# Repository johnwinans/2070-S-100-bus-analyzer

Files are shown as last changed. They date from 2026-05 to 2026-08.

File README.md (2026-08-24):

# 2070-S-100-bus-analyzer

A 120 channel S-100 bus logic analyzer

This project is based on the open source ["gusmanb" Logic Analyzer](https://github.com/gusmanb/logicanalyzer) project from Agustín Gimenez Bernad

I have started a [YouTube playlist](https://www.youtube.com/playlist?list=PL3by7evD3F51xCtWdVP3EZzuDttMwDS_U) of videos about this project and my testing of the board.

By using the software from the gusmanb/logicanalyzer repo, a 120 channel logic analyzer can be assembled by installing 5 Raspberry PI PICO boards on this S-100 card and accessed using a USB cables to a PC and/or WiFi as described in the above gusmanb github project Wiki.

Here is a [CSV of the project BOM](./2070-S-100-bus-analyzer.csv) with Dikikey order numbers. 

NOTE: I used generic male-headers that I got on Amazon and snapped to length.  I only use gold-plated headers.  Anything else is annoying.
Here is a link to the type that I use for most everything: https://a.co/d/02YRvqt7 (Hint: I snap them to length using a flat [Hakko Wire Cutters](https://a.co/d/055L9axg). Then use shunts to hold them in pairs, tripples, or whatever you need so they stay straight and aligned when soldering.)

# Rev 1.0

***NOTICE: As of April 20, 2026 Rev 1.0 of this design has been tested and is a fully functional board.  However, I am making some cosmetic tweaks (silkscreen, better testpoints, and I might shorten the PCB by 1/8"... see my self-critique in the above playlist.)  I will post a release (and remove this message) when I consider it in final form.***

# Rev 2.0

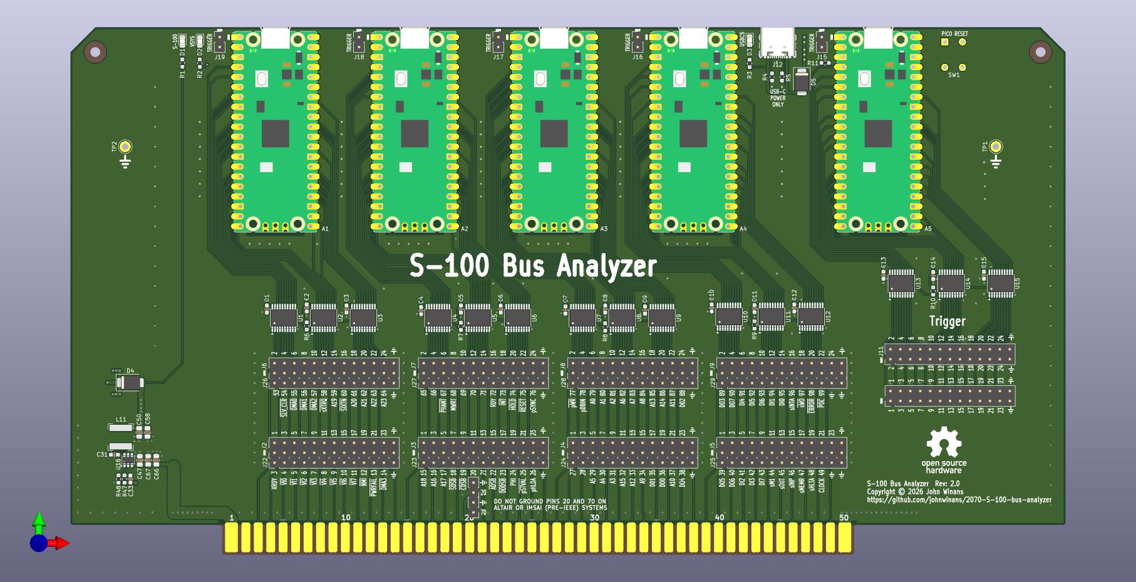
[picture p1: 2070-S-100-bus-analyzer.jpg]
PCB image


***NOTE: This is a release in progress.  It has not yet been tested.***

## Changes
- Change the board height to 5.0 inches to better fit into IEEE card cages.
- Change to use 3-row headers so that signals can be connected to a trigger input at the same time as the normal analyzedr channel with simpler jumper wires.
- Remove the alternate regulator option.
- Add special headers for pins 20 and 70 to make their purpose more obvious.
- Change to use thru-hole ground test-points for easier use with gator-clips.
- Use larger fonts and better-center the signal names.

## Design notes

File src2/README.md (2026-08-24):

# PICO Logic Analyzer Firmware and Applications

This software is based on the [Dr.G Logic Analyzer](https://github.com/gusmanb/logicanalyzer) but altered to add new features.
This implementation uses a protocol that is not compatible with the Dr.G GUI application.

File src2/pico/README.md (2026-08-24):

# A PICO Logic Analyzer

NOTE: This software is based on the [Dr.G Logic Analyzer](https://github.com/gusmanb/logicanalyzer) but altered to add new features.
This implementation uses a protocol that is not compatible with the Dr.G GUI application.

This has been verified by building on a Raspberry PI 4B running Trixie.

This is pre-configured for a PICO2.  
Adjust your build if needed by editing `LogicAnalyzer_Build_Settings.cmake`

1. Install the PICO development toolchain as described at: https://github.com/raspberrypi/pico-setup
1. Clone this REPO and build it using the above PICO toolchain from this directory:
```
mkdir build
cd build
cmake ..
make
```
1. Install the firmware on your PICO: power up your PICO while holding down the BOOTSEL button and then uising `picotool`:
```
picotool load LogicAnalyzer.uf2 -vx
```

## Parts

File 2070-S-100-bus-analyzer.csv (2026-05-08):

Reference | Qty | Value | Exclude from BOM | Footprint | Datasheet | Description | Digi-Key_PN | MPN | Manufacturer
TP1,TP2 | 2 | TestPoint |  | TestPoint:TestPoint_Keystone_5010-5014_Multipurpose |  |  | 2019-RCWCTECT-ND
LOGO1 | 1 | OSHW_Logo | Excluded from BOM | Symbol:OSHW-Logo_11.4x12mm_SilkScreen
J1 | 1 | S-100 Edge Connector | Excluded from BOM | S100-footprints:S100-Edge-Connector
SW1 | 1 | SW_MEC_5E |  | S100-footprints:tactile | https://www.te.com/commerce/DocumentDelivery/DDEController?Action=srchrtrv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 | SWITCH TACTILE SPST-NO 0.05A 24V | 450-1940-ND | 1-1825910-5 | TE Connectivity ALCOSWITCH Switches
R48 | 1 | 30K1 |  | Resistor_SMD:R_0603_1608Metric_Pad0.98x0.95mm_HandSolder | https://yageogroup.com/content/datasheet/asset/file/PYU-RT_1-TO-0-01_ROHS_L | RES SMD 30.1K OHM 1% 1/10W 0603 | 13-RT0603FRE0730K1LCT-ND | RT0603FRE0730K1L | YAGEO
R47 | 1 | 158K |  | Resistor_SMD:R_0603_1608Metric_Pad0.98x0.95mm_HandSolder | https://yageogroup.com/content/datasheet/asset/file/PYU-RT_1-TO-0-01_ROHS_L | RES SMD 158K OHM 1% 1/10W 0603 | 13-RT0603FRE07158KLCT-ND | RT0603FRE07158KL | YAGEO
R11 | 1 | 2K2 |  | Resistor_SMD:R_0603_1608Metric_Pad0.98x0.95mm_HandSolder |  |  | 311-2.20KHRCT-ND | RC0603FR-072K2L | YAGEO
R4,R5 | 2 | 5K1 |  | Resistor_SMD:R_0603_1608Metric_Pad0.98x0.95mm_HandSolder |  |  | CR0603-FX-510ELFCT-ND | CR0603-FX-5110ELF | Bourns Inc.
R1,R2,R3,R6,R7,R8,R9,R10 | 8 | 1K |  | Resistor_SMD:R_0603_1608Metric_Pad0.98x0.95mm_HandSolder | https://yageogroup.com/content/datasheet/asset/file/PYU-RC_GROUP_51_ROHS_L | RES SMD 1K OHM 1% 1/10W 0603 | 311-1.00KHRCT-ND | RC0603FR-071KL | Yageo
U16 | 1 | AP63300 |  | Package_TO_SOT_SMD:SOT-23-6 | https://www.diodes.com/assets/Datasheets/AP63300-AP63301.pdf | IC REG BUCK ADJ 3A TSOT26 | 31-AP63301WU-7CT-ND | AP63301WU-7 | Diodes Incorporated
U1,U2,U3,U4,U5,U6,U7,U8,U9,U10,U11,U12,U13,U14,U15 | 15 | 74LVCH245APW,118 |  | Package_SO:TSSOP-20_4.4x6.5mm_P0.65mm | https://assets.nexperia.com/documents/data-sheet/74LVC_LVCH245A.pdf | IC TXRX NON-INVERT 3.6V 20-TSSOP | 1727-4041-1-ND | 74LVCH245APW,118 | Nexperia USA Inc.
H1,H2 | 2 | Card Ejector |  | MountingHole:MountingHole_2.5mm | https://mm.digikey.com/Volume0/opasdata/d220001/medias/docus/6722/CP-2X_D1.pdf | CARD EJECTOR PCB 1.13" .063" WHT | 492-1025-ND | CP-26 WE | Bivar Inc.
A1,A2,A3,A4,A5 | 5 | RaspberryPi_Pico |  | Module:RaspberryPi_Pico_Common_Unspecified | https://datasheets.raspberrypi.com/pico/pico-datasheet.pdf | RASPBERRY PI PICO 2 RP2350 | 2648-SC1631CT-ND | 2648-SC1631CT-ND | Raspberry Pi
D1,D2,D3 | 3 | LED_Filled |  | LED_SMD:LED_0805_2012Metric_Pad1.15x1.40mm_HandSolder | https://look.ams-osram.com/m/2da6f2ceeebf8fac/original/LG-R971.pdf | LED GREEN DIFFUSED 0805 SMD | 475-LGR971-KN-1CT-ND | LG R971-KN-1-0-20-R18 | ams-OSRAM USA INC.
L11 | 1 | 6.8uH |  | Inductor_SMD:L_Bourns-SRN6028 | https://product.tdk.com/en/system/files | FIXED IND 6.8UH 3.6A 47 MOHM SMD | 445-173057-1-ND | VLS6045EX-6R8M | TDK Corporation
D4,D5 | 2 | SS56F |  | Diode_SMD:D_SMB | https://mm.digikey.com/Volume0/opasdata/d220001/medias/docus/6808/SS56F%20SMAF.PDF | 60V INDEPENDENT TYPE 700MV@5A 5A | 5399-SS56FCT-ND | SS56F | Shenzhen Slkormicro Semicon Co., Ltd.
J12 | 1 | USB4105-GF-A |  | Connector_USB:USB_C_Receptacle_GCT_USB4105-xx-A_16P_TopMnt_Horizontal | https://gct.co/files/drawings/usb4105.pdf | CONN RCP USB2.0 TYP C 16P SMD RA | 2073-USB4105-GF-ACT-ND | USB4105-GF-A | GCT
J2,J3,J4,J5,J6,J7,J8,J9,J10,J11 | 10 | Conn_02x13_Odd_Even |  | Connector_PinHeader_2.54mm:PinHeader_2x13_P2.54mm_Vertical | ~ | Generic connector, double row, 02x13, odd/even pin numbering scheme (row 1 odd numbers, row 2 even numbers), script generated (kicad-library-utils/schlib/autogen/connector/)
J22,J23,J24,J25,J26,J27,J28,J29 | 8 | Conn_01x13 |  | Connector_PinHeader_2.54mm:PinHeader_1x13_P2.54mm_Vertical | ~ | Generic connector, single row, 01x13, script generated (kicad-library-utils/schlib/autogen/connector/)
J13,J14,J15,J16,J17,J18,J19 | 7 | Conn_01x02 |  | Connector_PinHeader_2.54mm:PinHeader_1x02_P2.54mm_Vertical | ~ | Generic connector, single row, 01x02, script generated (kicad-library-utils/schlib/autogen/connector/)
C66,C67 | 2 | 22uF 35V |  | Capacitor_SMD:C_0805_2012Metric_Pad1.18x1.45mm_HandSolder | https://product.tdk.com/system/files/dam/doc/product/capacitor/ceramic/mlcc/catalog/mlcc_commercial_general_en.pdf | CAP CER 22UF 35V X5R 0805 | 445-14428-1-ND | C2012X5R1V226M125AC | TDK
C50,C58 | 2 | 22uF |  | Capacitor_SMD:C_0805_2012Metric_Pad1.18x1.45mm_HandSolder | https://search.murata.co.jp/Ceramy/image/img/A01X/G101/ENG/GRM21BR61A226ME44-01.pdf | CAP CER 22UF 10V X5R 0805 | 490-10746-1-ND | GRM21BR61A226ME44L | Murata Electronics
C47 | 1 | 10uF 25V |  | Capacitor_SMD:C_0805_2012Metric_Pad1.18x1.45mm_HandSolder | https://mm.digikey.com/Volume0/opasdata/d220001/medias/docus/4888/TMK212BBJ106KG-T_SS.pdf | CAP CER 10UF 25V X5R 0805 | 587-2985-1-ND | TMK212BBJ106KG-T | Taiyo Yuden
C33 | 1 | 47pF |  | Capacitor_SMD:C_0603_1608Metric_Pad1.08x0.95mm_HandSolder | https://mm.digikey.com/Volume0/opasdata/d220001/medias/docus/609/CL10C470JB8NNNC_Spec.pdf | CAP CER 47PF 50V C0G/NP0 0603 | 1276-1037-1-ND | CL10C470JB8NNNC | Samsung Electro-Mechanics
C1,C2,C3,C4,C5,C6,C7,C8,C9,C10,C11,C12,C13,C14,C15,C31 | 16 | .1uF |  | Capacitor_SMD:C_0603_1608Metric_Pad1.08x0.95mm_HandSolder | ~ | CAP CER 0.1UF 25V X5R 0603 | 445-6854-1-ND | C1608X5R1E104K | TDK Corporation

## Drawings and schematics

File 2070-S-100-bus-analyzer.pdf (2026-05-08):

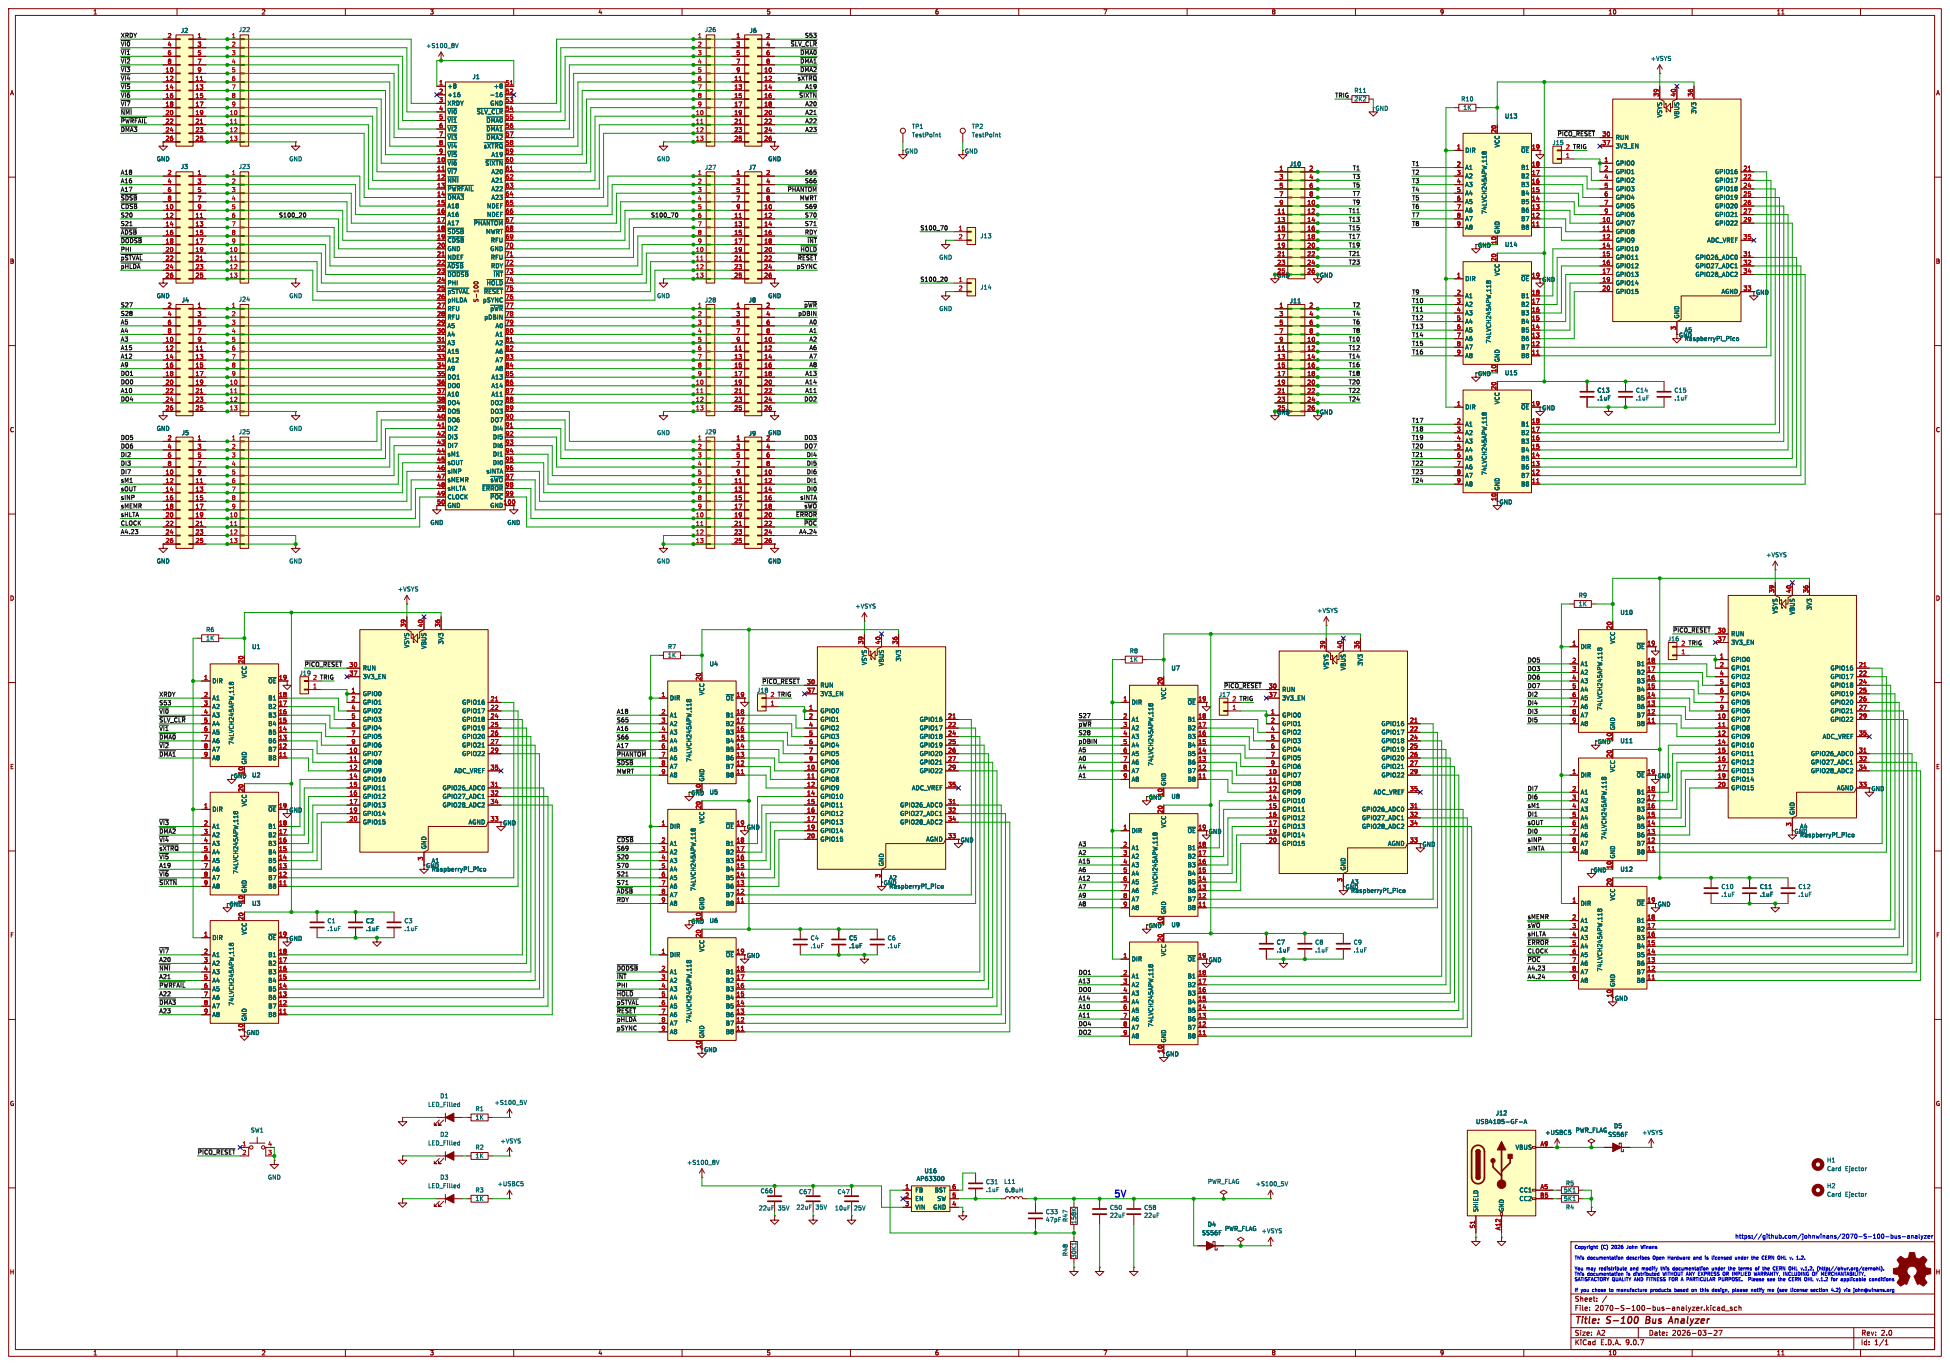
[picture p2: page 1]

J1 +8 1 +16 2 XRDY 3 ~{VI0} 4 ~{VI1} 5 ~{VI2} 6 ~{VI3} 7 ~{VI4} 8 ~{VI5} 9 ~{VI6} 10 ~{VI7} 11 ~{NMI} 12 ~{PWRFAIL} 13 ~{DMA3} 14 A18 15 A16 16 A17 17 ~{SDSB} 18 ~{CDSB} 19 GND 20 NDEF 21 ~{ADSB} 22 ~{DODSB} 23 PHI 24 ~{pSTVAL} 25
GND S-100 +8 1 +16 2 XRDY 3 ~{VI0} 4 ~{VI1} 5 ~{VI2} 6 ~{VI3} 7 ~{VI4} 8 ~{VI5} 9 ~{VI6} 10 ~{VI7} 11 ~{NMI} 12 ~{PWRFAIL} 13 ~{DMA3} 14 A18 15 A16 16 A17 17 ~{SDSB} 18 ~{CDSB} 19 GND 20 NDEF 21 ~{ADSB} 22 ~{DODSB} 23 PHI 24 ~{pSTVAL} 25
-16 52 GND 53 ~{SLV_CLR} 54 ~{DMA0} 55 ~{DMA1} 56 ~{DMA2} 57 ~{sXTRQ} 58 A19 59 ~{SIXTN} 60 A20 61 A21 62 A22 63 A23 64 NDEF 65 NDEF 66 ~{PHANTOM} 67 MWRT 68 RFU 69 GND 70 RFU 71 RDY 72 ~{INT} 73 ~{HOLD} 74 ~{RESET} 75

sINTA 96 ~{sWO} 97 ~{ERROR} 98 ~{POC} 99 GND100

sINTA 96 ~{sWO} 97 ~{ERROR} 98 ~{POC} 99 GND100GND

H2 Card Ejector H1 Card Ejector

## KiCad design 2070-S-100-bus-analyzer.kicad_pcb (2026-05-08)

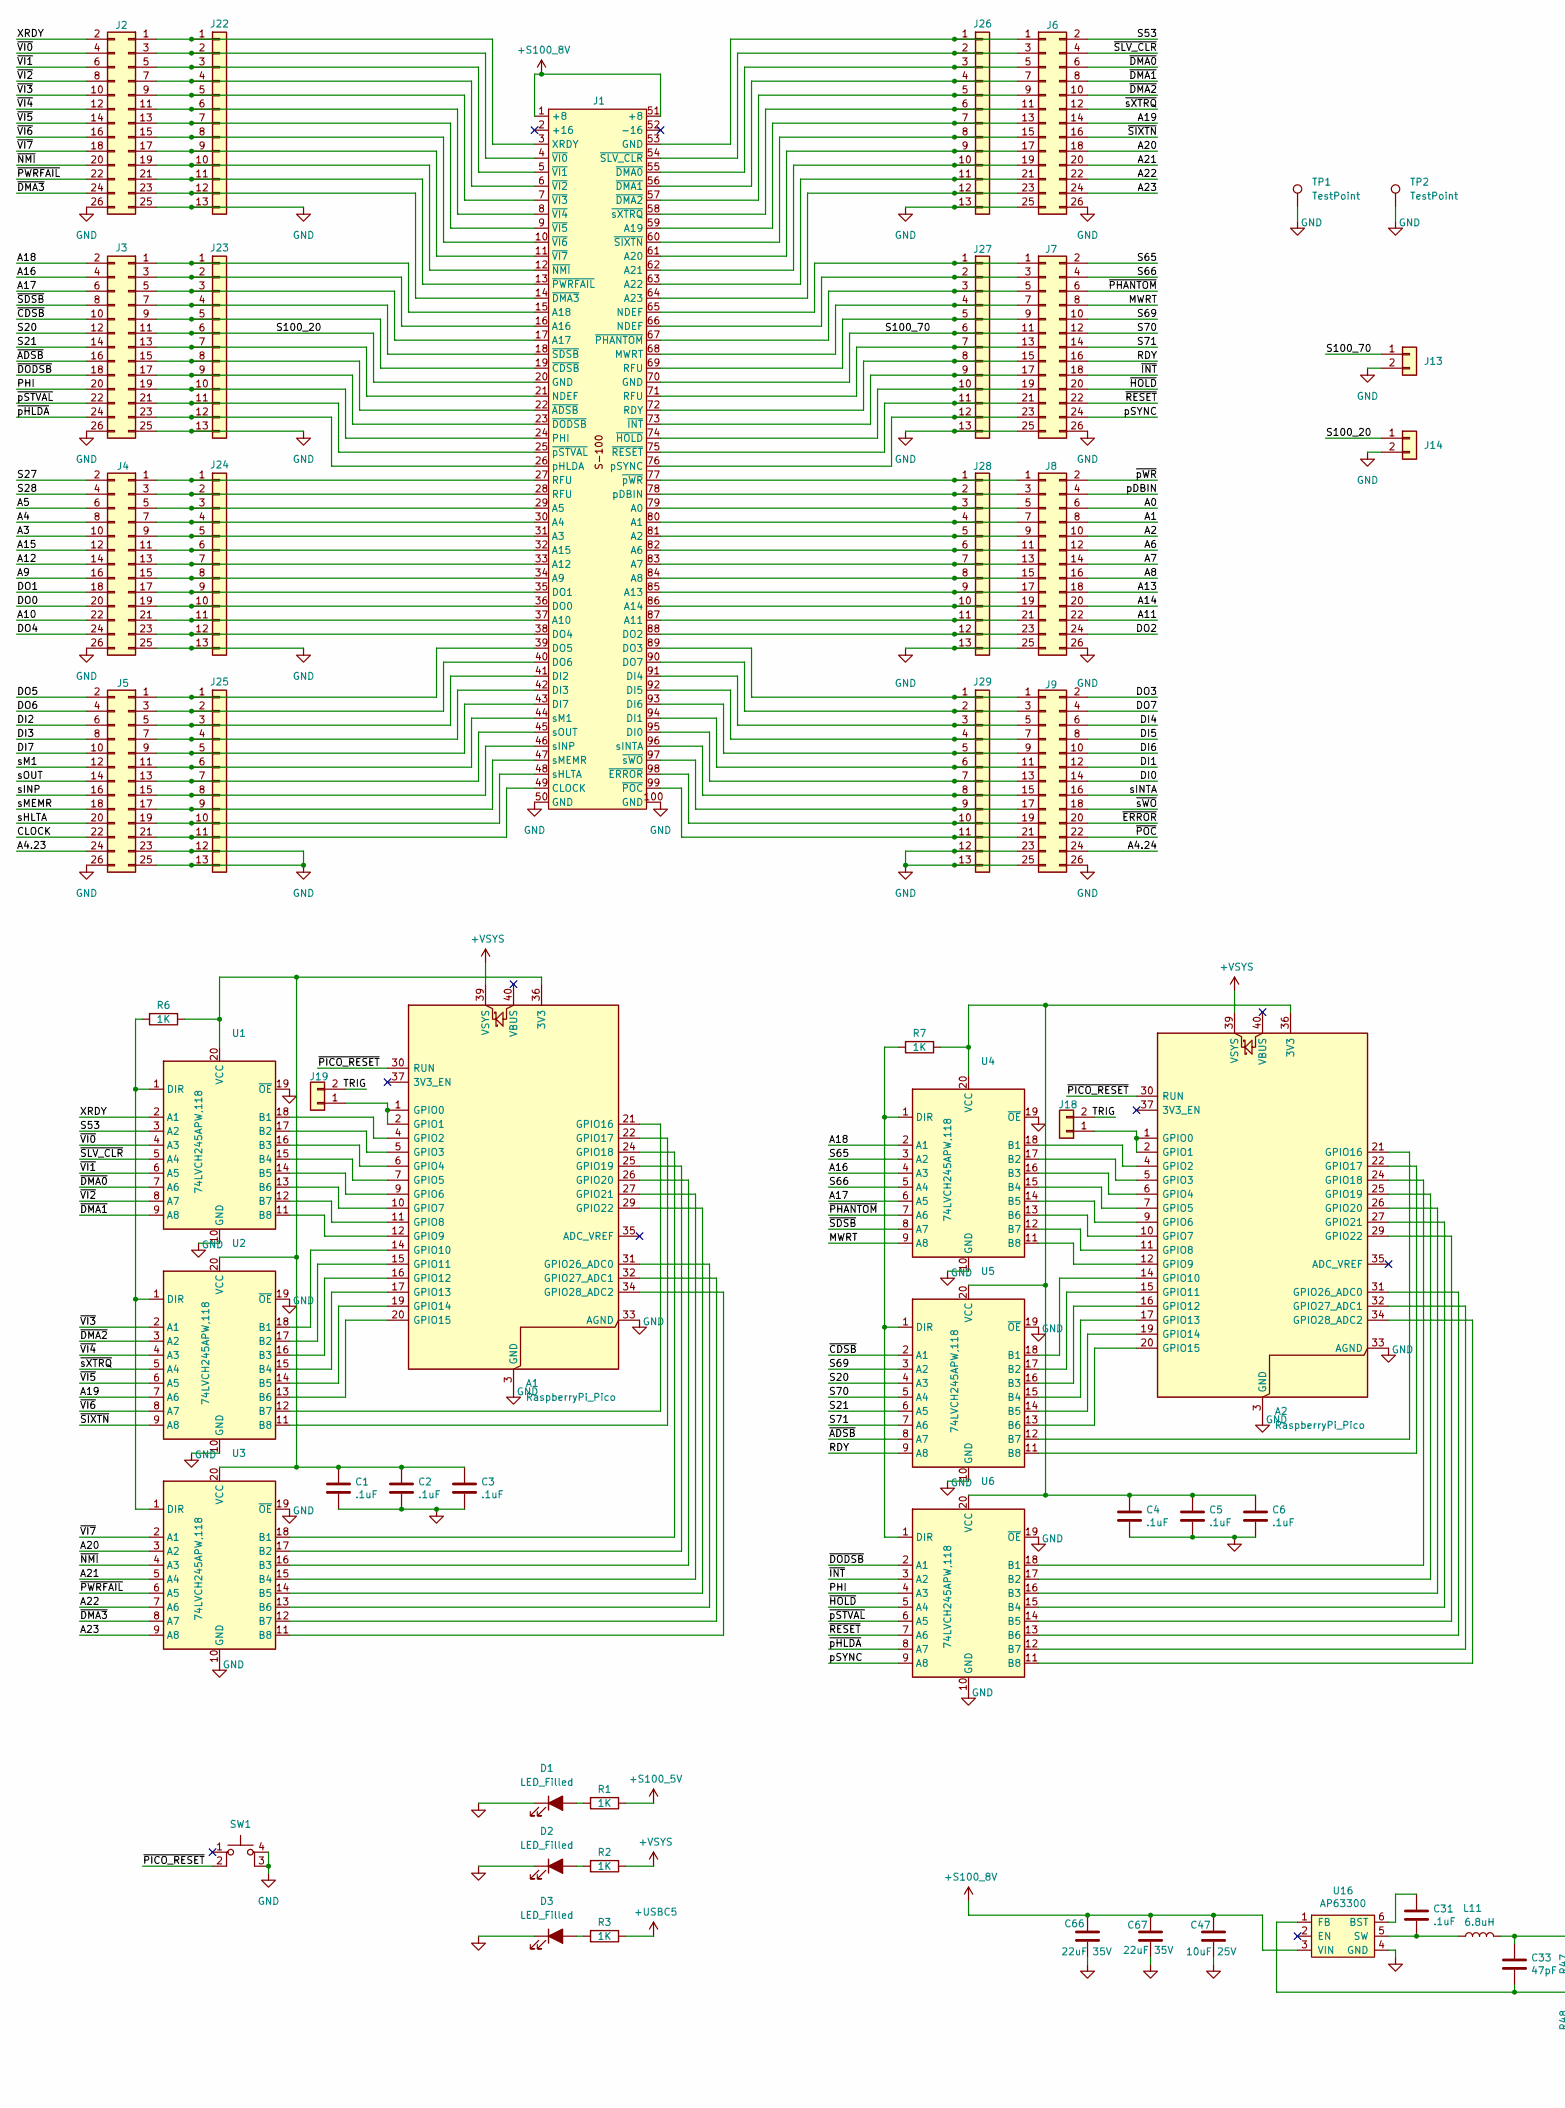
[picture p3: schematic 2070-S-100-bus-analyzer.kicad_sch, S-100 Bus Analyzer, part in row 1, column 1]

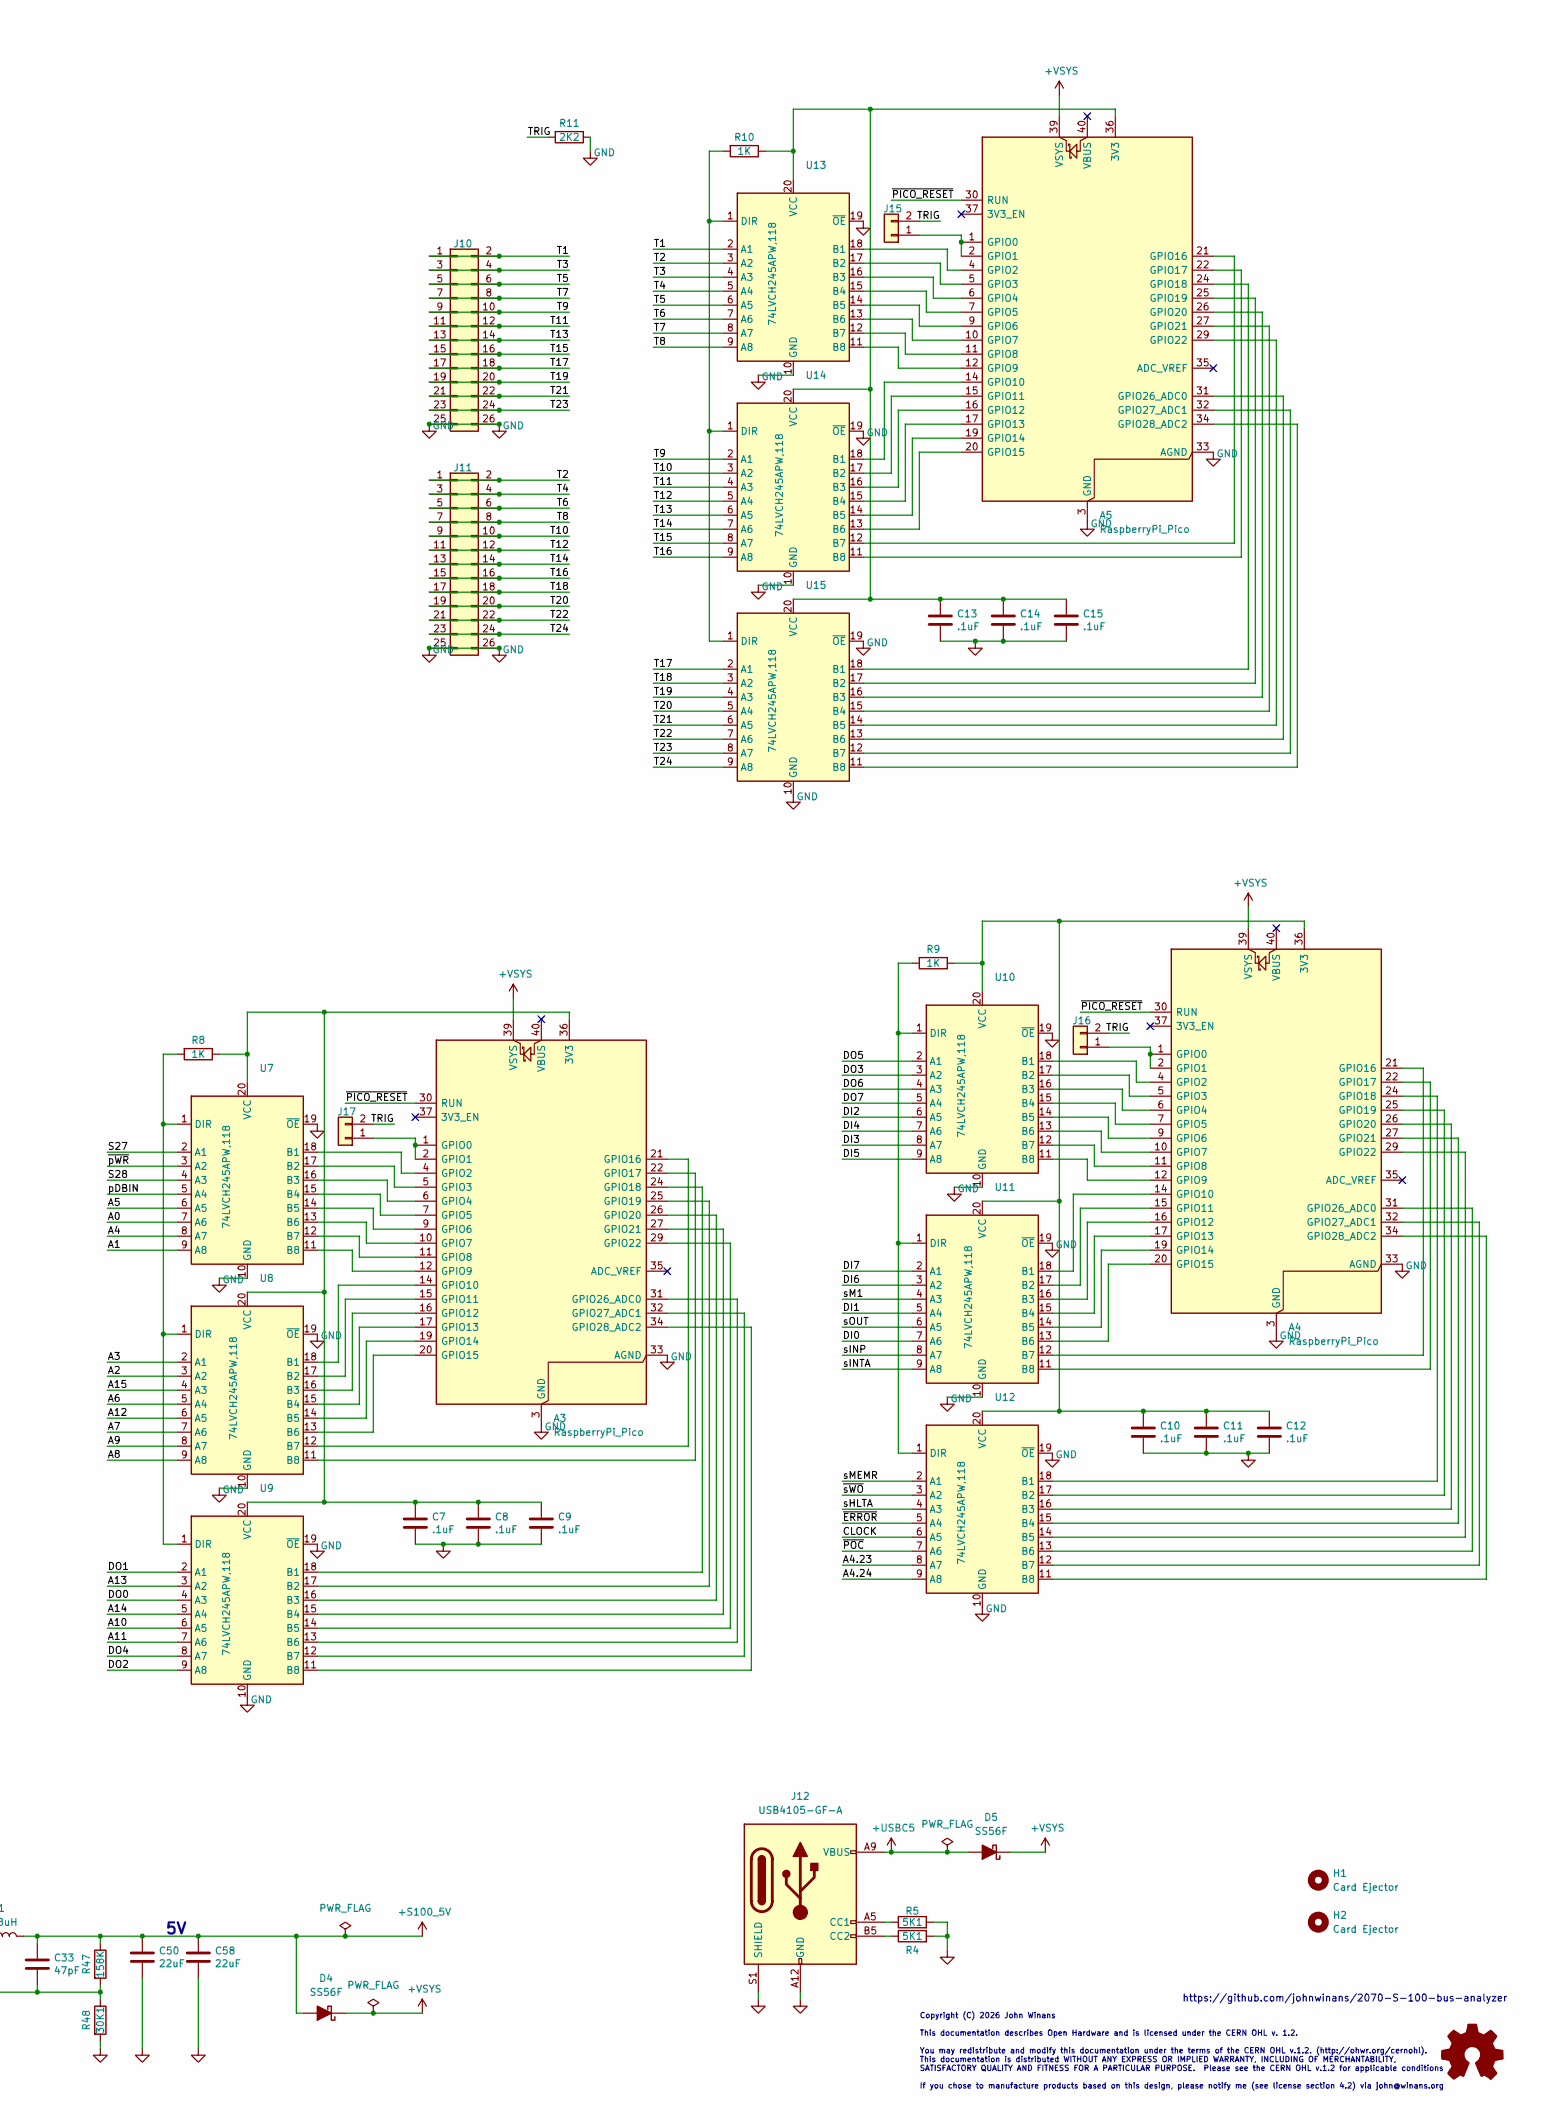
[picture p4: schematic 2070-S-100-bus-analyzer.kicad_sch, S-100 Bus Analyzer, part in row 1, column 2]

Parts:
A1, A2, A3, A4, A5: RaspberryPi_Pico; RaspberryPi_Pico_Common_Unspecified; MPN 2648-SC1631CT-ND; Digi-Key_PN 2648-SC1631CT-ND
C1, C2, C3, C4, C5, C6, C7, C8, C9, C10, C11, C12, C13, C14, C15, C31: .1uF; C_0603_1608Metric_Pad1.08x0.95mm_HandSolder; MPN C1608X5R1E104K; Digi-Key_PN 445-6854-1-ND
C33: 47pF; C_0603_1608Metric_Pad1.08x0.95mm_HandSolder; MPN CL10C470JB8NNNC; Digi-Key_PN 1276-1037-1-ND
C47: 10uF 25V; C_0805_2012Metric_Pad1.18x1.45mm_HandSolder; MPN TMK212BBJ106KG-T; Digi-Key_PN 587-2985-1-ND
C50, C58: 22uF; C_0805_2012Metric_Pad1.18x1.45mm_HandSolder; MPN GRM21BR61A226ME44L; Digi-Key_PN 490-10746-1-ND
C66, C67: 22uF 35V; C_0805_2012Metric_Pad1.18x1.45mm_HandSolder; MPN C2012X5R1V226M125AC; Digi-Key_PN 445-14428-1-ND
D1, D2, D3: LED_Filled; LED_0805_2012Metric_Pad1.15x1.40mm_HandSolder; MPN LG R971-KN-1-0-20-R18; Digi-Key_PN 475-LGR971-KN-1CT-ND
D4, D5: SS56F; D_SMB; MPN SS56F; Digi-Key_PN 5399-SS56FCT-ND
H1, H2: Card Ejector; MountingHole_2.5mm; MPN CP-26 WE; Digi-Key_PN 492-1025-ND
J1: S-100 Edge Connector; S100-Edge-Connector
J2, J3, J4, J5, J6, J7, J8, J9, J10, J11: Conn_02x13_Odd_Even; PinHeader_2x13_P2.54mm_Vertical
J12: USB4105-GF-A; USB_C_Receptacle_GCT_USB4105-xx-A_16P_TopMnt_Horizontal; MPN USB4105-GF-A; Digi-Key_PN 2073-USB4105-GF-ACT-ND
J13, J14, J15, J16, J17, J18, J19: Conn_01x02; PinHeader_1x02_P2.54mm_Vertical
J22, J23, J24, J25, J26, J27, J28, J29: Conn_01x13; PinHeader_1x13_P2.54mm_Vertical
L11: 6.8uH; L_Bourns-SRN6028; MPN VLS6045EX-6R8M; Digi-Key_PN 445-173057-1-ND
LOGO1: OSHW_Logo; OSHW-Logo_11.4x12mm_SilkScreen
R1, R2, R3, R6, R7, R8, R9, R10: 1K; R_0603_1608Metric_Pad0.98x0.95mm_HandSolder; MPN RC0603FR-071KL; Digi-Key_PN 311-1.00KHRCT-ND
R4, R5: 5K1; R_0603_1608Metric_Pad0.98x0.95mm_HandSolder; MPN CR0603-FX-5110ELF; Digi-Key_PN CR0603-FX-510ELFCT-ND
R11: 2K2; R_0603_1608Metric_Pad0.98x0.95mm_HandSolder; MPN RC0603FR-072K2L; Digi-Key_PN 311-2.20KHRCT-ND
R47: 158K; R_0603_1608Metric_Pad0.98x0.95mm_HandSolder; MPN RT0603FRE07158KL; Digi-Key_PN 13-RT0603FRE07158KLCT-ND
R48: 30K1; R_0603_1608Metric_Pad0.98x0.95mm_HandSolder; MPN RT0603FRE0730K1L; Digi-Key_PN 13-RT0603FRE0730K1LCT-ND
SW1: SW_MEC_5E; tactile; MPN 1-1825910-5; Digi-Key_PN 450-1940-ND
TP1, TP2: TestPoint; TestPoint_Keystone_5010-5014_Multipurpose; Digi-Key_PN 2019-RCWCTECT-ND
U1, U2, U3, U4, U5, U6, U7, U8, U9, U10, U11, U12, U13, U14, U15: 74LVCH245APW,118; TSSOP-20_4.4x6.5mm_P0.65mm; MPN 74LVCH245APW,118; Digi-Key_PN 1727-4041-1-ND
U16: AP63300; SOT-23-6; MPN AP63301WU-7; Digi-Key_PN 31-AP63301WU-7CT-ND

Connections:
+S100_5V: C33.1, C50.1, C58.1, D4.2 (A), L11.2, R1.1, R47.1
+S100_8V: C47.1, C66.1, C67.1, J1.1 (+8), J1.51 (+8), U16.3 (VIN)
+USBC5: D5.2 (A), J12.A4 (VBUS), J12.A9 (VBUS), J12.B4 (VBUS), J12.B9 (VBUS), R3.1
+VSYS: A1.39 (VSYS), A2.39 (VSYS), A3.39 (VSYS), A4.39 (VSYS), A5.39 (VSYS), D4.1 (K), D5.1 (K), R2.1
/A0: J8.6, U7.7 (A6)
/A1: J8.8, U7.9 (A8)
/A2: J8.10, U8.3 (A2)
/A3: J4.10, U8.2 (A1)
/A4: J4.8, U7.8 (A7)
/A4.23: J5.24, U12.8 (A7)
/A4.24: J9.24, U12.9 (A8)
/A5: J4.6, U7.6 (A5)
/A6: J8.12, U8.5 (A4)
/A7: J8.14, U8.7 (A6)
/A8: J8.16, U8.9 (A8)
/A9: J4.16, U8.8 (A7)
/A10: J4.22, U9.6 (A5)
/A11: J8.22, U9.7 (A6)
/A12: J4.14, U8.6 (A5)
/A13: J8.18, U9.3 (A2)
/A14: J8.20, U9.5 (A4)
/A15: J4.12, U8.4 (A3)
/A16: J3.4, U4.4 (A3)
/A17: J3.6, U4.6 (A5)
/A18: J3.2, U4.2 (A1)
/A19: J6.14, U2.7 (A6)
/A20: J6.18, U3.3 (A2)
/A21: J6.20, U3.5 (A4)
/A22: J6.22, U3.7 (A6)
/A23: J6.24, U3.9 (A8)
/CLOCK: J5.22, U12.6 (A5)
/DI0: J9.14, U11.7 (A6)
/DI1: J9.12, U11.5 (A4)
/DI2: J5.6, U10.6 (A5)
/DI3: J5.8, U10.8 (A7)
/DI4: J9.6, U10.7 (A6)
/DI5: J9.8, U10.9 (A8)
/DI6: J9.10, U11.3 (A2)
/DI7: J5.10, U11.2 (A1)
/DO0: J4.20, U9.4 (A3)
/DO1: J4.18, U9.2 (A1)
/DO2: J8.24, U9.9 (A8)
/DO3: J9.2, U10.3 (A2)
/DO4: J4.24, U9.8 (A7)
/DO5: J5.2, U10.2 (A1)
/DO6: J5.4, U10.4 (A3)
/DO7: J9.4, U10.5 (A4)
/MWRT: J7.8, U4.9 (A8)
/PHI: J3.20, U6.4 (A3)
/RDY: J7.16, U5.9 (A8)
/S20: J3.12, U5.4 (A3)
/S21: J3.14, U5.6 (A5)
/S27: J4.2, U7.2 (A1)
/S28: J4.4, U7.4 (A3)
/S53: J6.2, U1.3 (A2)
/S65: J7.2, U4.3 (A2)
/S66: J7.4, U4.5 (A4)
/S69: J7.10, U5.3 (A2)
/S70: J7.12, U5.5 (A4)
/S71: J7.14, U5.7 (A6)
/S100_20: J1.20 (GND), J3.11, J14.1, J23.6
/S100_70: J1.70 (GND), J7.11, J13.1, J27.6
/T1: J10.1, J10.2, U13.2 (A1)
/T2: J11.1, J11.2, U13.3 (A2)
/T3: J10.3, J10.4, U13.4 (A3)
/T4: J11.3, J11.4, U13.5 (A4)
/T5: J10.5, J10.6, U13.6 (A5)
/T6: J11.5, J11.6, U13.7 (A6)
/T7: J10.7, J10.8, U13.8 (A7)
/T8: J11.7, J11.8, U13.9 (A8)
/T9: J10.9, J10.10, U14.2 (A1)
/T10: J11.9, J11.10, U14.3 (A2)
/T11: J10.11, J10.12, U14.4 (A3)
/T12: J11.11, J11.12, U14.5 (A4)
/T13: J10.13, J10.14, U14.6 (A5)
/T14: J11.13, J11.14, U14.7 (A6)
/T15: J10.15, J10.16, U14.8 (A7)
/T16: J11.15, J11.16, U14.9 (A8)
/T17: J10.17, J10.18, U15.2 (A1)
/T18: J11.17, J11.18, U15.3 (A2)
/T19: J10.19, J10.20, U15.4 (A3)
/T20: J11.19, J11.20, U15.5 (A4)
/T21: J10.21, J10.22, U15.6 (A5)
/T22: J11.21, J11.22, U15.7 (A6)
/T23: J10.23, J10.24, U15.8 (A7)
/T24: J11.23, J11.24, U15.9 (A8)
/TRIG: J15.2, J16.2, J17.2, J18.2, J19.2, R11.2
/XRDY: J2.2, U1.2 (A1)
/pDBIN: J8.4, U7.5 (A4)
/pSYNC: J7.24, U6.9 (A8)
/sHLTA: J5.20, U12.4 (A3)
/sINP: J5.16, U11.8 (A7)
/sINTA: J9.16, U11.9 (A8)
/sM1: J5.12, U11.4 (A3)
/sMEMR: J5.18, U12.2 (A1)
/sOUT: J5.14, U11.6 (A5)
/~ADSB: J3.16, U5.8 (A7)
/~CDSB: J3.10, U5.2 (A1)
/~DMA0: J6.6, U1.7 (A6)
/~DMA1: J6.8, U1.9 (A8)
/~DMA2: J6.10, U2.3 (A2)
/~DMA3: J2.24, U3.8 (A7)
/~DODSB: J3.18, U6.2 (A1)
/~ERROR: J9.20, U12.5 (A4)
/~HOLD: J7.20, U6.5 (A4)
/~INT: J7.18, U6.3 (A2)
/~NMI: J2.20, U3.4 (A3)
/~PHANTOM: J7.6, U4.7 (A6)
/~PICO_RESET: A1.30 (RUN), A2.30 (RUN), A3.30 (RUN), A4.30 (RUN), A5.30 (RUN), SW1.2
/~POC: J9.22, U12.7 (A6)
/~PWRFAIL: J2.22, U3.6 (A5)
/~RESET: J7.22, U6.7 (A6)
/~SDSB: J3.8, U4.8 (A7)
/~SIXTN: J6.16, U2.9 (A8)
/~SLV_CLR: J6.4, U1.5 (A4)
/~VI0: J2.4, U1.4 (A3)
/~VI1: J2.6, U1.6 (A5)
/~VI2: J2.8, U1.8 (A7)
/~VI3: J2.10, U2.2 (A1)
/~VI4: J2.12, U2.4 (A3)
/~VI5: J2.14, U2.6 (A5)
/~VI6: J2.16, U2.8 (A7)
/~VI7: J2.18, U3.2 (A1)
/~pHLDA: J3.24, U6.8 (A7)
/~pSTVAL: J3.22, U6.6 (A5)
/~pWR: J8.2, U7.3 (A2)
/~sWO: J9.18, U12.3 (A2)
/~sXTRQ: J6.12, U2.5 (A4)
GND: A1.3 (GND), A1.8 (GND), A1.13 (GND), A1.18 (GND), A1.23 (GND), A1.28 (GND), A1.33 (AGND), A1.38 (GND), A2.3 (GND), A2.8 (GND), A2.13 (GND), A2.18 (GND), A2.23 (GND), A2.28 (GND), A2.33 (AGND), A2.38 (GND), A3.3 (GND), A3.8 (GND), A3.13 (GND), A3.18 (GND), A3.23 (GND), A3.28 (GND), A3.33 (AGND), A3.38 (GND), A4.3 (GND), A4.8 (GND), A4.13 (GND), A4.18 (GND), A4.23 (GND), A4.28 (GND), A4.33 (AGND), A4.38 (GND), A5.3 (GND), A5.8 (GND), A5.13 (GND), A5.18 (GND), A5.23 (GND), A5.28 (GND), A5.33 (AGND), A5.38 (GND), C1.2, C2.2, C3.2, C4.2, C5.2, C6.2, C7.2, C8.2, C9.2, C10.2, C11.2, C12.2, C13.2, C14.2, C15.2, C47.2, C50.2, C58.2, C66.2, C67.2, D1.1 (K), D2.1 (K), D3.1 (K), J1.50 (GND), J1.100 (GND), J2.25, J2.26, J3.25, J3.26, J4.25, J4.26, J5.23, J5.25, J5.26, J6.25, J6.26, J7.25, J7.26, J8.25, J8.26, J9.23, J9.25, J9.26, J10.25, J10.26, J11.25, J11.26, J12.A1 (GND), J12.A12 (GND), J12.B1 (GND), J12.B12 (GND), J12.S1 (SHIELD), J13.2, J14.2, J22.13, J23.13, J24.13, J25.12, J25.13, J26.13, J27.13, J28.13, J29.12, J29.13, R4.2, R5.2, R11.1, R48.2, SW1.3 (K), SW1.4 (A), TP1.1, TP2.1, U1.10 (GND), U1.19 (~OE), U2.10 (GND), U2.19 (~OE), U3.10 (GND), U3.19 (~OE), U4.10 (GND), U4.19 (~OE), U5.10 (GND), U5.19 (~OE), U6.10 (GND), U6.19 (~OE), U7.10 (GND), U7.19 (~OE), U8.10 (GND), U8.19 (~OE), U9.10 (GND), U9.19 (~OE), U10.10 (GND), U10.19 (~OE), U11.10 (GND), U11.19 (~OE), U12.10 (GND), U12.19 (~OE), U13.10 (GND), U13.19 (~OE), U14.10 (GND), U14.19 (~OE), U15.10 (GND), U15.19 (~OE), U16.4 (GND)
unnamed: A1.36 (3V3), C1.1, C2.1, C3.1, R6.1, U1.20 (VCC), U2.20 (VCC), U3.20 (VCC)
unnamed: A1.1 (GPIO0), A1.2 (GPIO1), J19.1
unnamed: A1.4 (GPIO2), U1.18 (B1)
unnamed: A1.5 (GPIO3), U1.17 (B2)
unnamed: A1.6 (GPIO4), U1.16 (B3)
unnamed: A1.7 (GPIO5), U1.15 (B4)
unnamed: A1.9 (GPIO6), U1.14 (B5)
unnamed: A1.10 (GPIO7), U1.13 (B6)
unnamed: A1.11 (GPIO8), U1.12 (B7)
unnamed: A1.12 (GPIO9), U1.11 (B8)
unnamed: A1.14 (GPIO10), U2.18 (B1)
unnamed: A1.15 (GPIO11), U2.17 (B2)
unnamed: A1.16 (GPIO12), U2.16 (B3)
unnamed: A1.17 (GPIO13), U2.15 (B4)
unnamed: A1.19 (GPIO14), U2.14 (B5)
unnamed: A1.20 (GPIO15), U2.13 (B6)
unnamed: A1.21 (GPIO16), U2.12 (B7)
unnamed: A1.22 (GPIO17), U2.11 (B8)
unnamed: A1.24 (GPIO18), U3.18 (B1)
unnamed: A1.25 (GPIO19), U3.17 (B2)
unnamed: A1.26 (GPIO20), U3.16 (B3)
unnamed: A1.27 (GPIO21), U3.15 (B4)
unnamed: A1.29 (GPIO22), U3.14 (B5)
unnamed: A1.31 (GPIO26_ADC0), U3.13 (B6)
unnamed: A1.32 (GPIO27_ADC1), U3.12 (B7)
unnamed: A1.34 (GPIO28_ADC2), U3.11 (B8)
unnamed: A2.36 (3V3), C4.1, C5.1, C6.1, R7.1, U4.20 (VCC), U5.20 (VCC), U6.20 (VCC)
unnamed: A2.1 (GPIO0), A2.2 (GPIO1), J18.1
unnamed: A2.4 (GPIO2), U4.18 (B1)
unnamed: A2.5 (GPIO3), U4.17 (B2)
unnamed: A2.6 (GPIO4), U4.16 (B3)
unnamed: A2.7 (GPIO5), U4.15 (B4)
unnamed: A2.9 (GPIO6), U4.14 (B5)
unnamed: A2.10 (GPIO7), U4.13 (B6)
unnamed: A2.11 (GPIO8), U4.12 (B7)
unnamed: A2.12 (GPIO9), U4.11 (B8)
unnamed: A2.14 (GPIO10), U5.18 (B1)
unnamed: A2.15 (GPIO11), U5.17 (B2)
unnamed: A2.16 (GPIO12), U5.16 (B3)
unnamed: A2.17 (GPIO13), U5.15 (B4)
unnamed: A2.19 (GPIO14), U5.14 (B5)
unnamed: A2.20 (GPIO15), U5.13 (B6)
unnamed: A2.21 (GPIO16), U5.12 (B7)
unnamed: A2.22 (GPIO17), U5.11 (B8)
unnamed: A2.24 (GPIO18), U6.18 (B1)
unnamed: A2.25 (GPIO19), U6.17 (B2)
unnamed: A2.26 (GPIO20), U6.16 (B3)
unnamed: A2.27 (GPIO21), U6.15 (B4)
unnamed: A2.29 (GPIO22), U6.14 (B5)
unnamed: A2.31 (GPIO26_ADC0), U6.13 (B6)
unnamed: A2.32 (GPIO27_ADC1), U6.12 (B7)
unnamed: A2.34 (GPIO28_ADC2), U6.11 (B8)
unnamed: A3.36 (3V3), C7.1, C8.1, C9.1, R8.1, U7.20 (VCC), U8.20 (VCC), U9.20 (VCC)
unnamed: A3.1 (GPIO0), A3.2 (GPIO1), J17.1
unnamed: A3.4 (GPIO2), U7.18 (B1)
unnamed: A3.5 (GPIO3), U7.17 (B2)
unnamed: A3.6 (GPIO4), U7.16 (B3)
unnamed: A3.7 (GPIO5), U7.15 (B4)
unnamed: A3.9 (GPIO6), U7.14 (B5)
unnamed: A3.10 (GPIO7), U7.13 (B6)
unnamed: A3.11 (GPIO8), U7.12 (B7)
unnamed: A3.12 (GPIO9), U7.11 (B8)
unnamed: A3.14 (GPIO10), U8.18 (B1)
unnamed: A3.15 (GPIO11), U8.17 (B2)
unnamed: A3.16 (GPIO12), U8.16 (B3)
unnamed: A3.17 (GPIO13), U8.15 (B4)
unnamed: A3.19 (GPIO14), U8.14 (B5)
unnamed: A3.20 (GPIO15), U8.13 (B6)
unnamed: A3.21 (GPIO16), U8.12 (B7)
unnamed: A3.22 (GPIO17), U8.11 (B8)
unnamed: A3.24 (GPIO18), U9.18 (B1)
unnamed: A3.25 (GPIO19), U9.17 (B2)
unnamed: A3.26 (GPIO20), U9.16 (B3)
unnamed: A3.27 (GPIO21), U9.15 (B4)
unnamed: A3.29 (GPIO22), U9.14 (B5)
unnamed: A3.31 (GPIO26_ADC0), U9.13 (B6)
unnamed: A3.32 (GPIO27_ADC1), U9.12 (B7)
unnamed: A3.34 (GPIO28_ADC2), U9.11 (B8)
unnamed: A4.36 (3V3), C10.1, C11.1, C12.1, R9.1, U10.20 (VCC), U11.20 (VCC), U12.20 (VCC)
unnamed: A4.1 (GPIO0), A4.2 (GPIO1), J16.1
unnamed: A4.4 (GPIO2), U10.18 (B1)
unnamed: A4.5 (GPIO3), U10.17 (B2)
unnamed: A4.6 (GPIO4), U10.16 (B3)
unnamed: A4.7 (GPIO5), U10.15 (B4)
unnamed: A4.9 (GPIO6), U10.14 (B5)
unnamed: A4.10 (GPIO7), U10.13 (B6)
unnamed: A4.11 (GPIO8), U10.12 (B7)
unnamed: A4.12 (GPIO9), U10.11 (B8)
unnamed: A4.14 (GPIO10), U11.18 (B1)
unnamed: A4.15 (GPIO11), U11.17 (B2)
unnamed: A4.16 (GPIO12), U11.16 (B3)
unnamed: A4.17 (GPIO13), U11.15 (B4)
unnamed: A4.19 (GPIO14), U11.14 (B5)
unnamed: A4.20 (GPIO15), U11.13 (B6)
unnamed: A4.21 (GPIO16), U11.12 (B7)
unnamed: A4.22 (GPIO17), U11.11 (B8)
unnamed: A4.24 (GPIO18), U12.18 (B1)
unnamed: A4.25 (GPIO19), U12.17 (B2)
unnamed: A4.26 (GPIO20), U12.16 (B3)
unnamed: A4.27 (GPIO21), U12.15 (B4)
unnamed: A4.29 (GPIO22), U12.14 (B5)
unnamed: A4.31 (GPIO26_ADC0), U12.13 (B6)
unnamed: A4.32 (GPIO27_ADC1), U12.12 (B7)
unnamed: A4.34 (GPIO28_ADC2), U12.11 (B8)
unnamed: A5.36 (3V3), C13.1, C14.1, C15.1, R10.1, U13.20 (VCC), U14.20 (VCC), U15.20 (VCC)
unnamed: A5.1 (GPIO0), A5.2 (GPIO1), J15.1
unnamed: A5.4 (GPIO2), U13.18 (B1)
unnamed: A5.5 (GPIO3), U13.17 (B2)
unnamed: A5.6 (GPIO4), U13.16 (B3)
unnamed: A5.7 (GPIO5), U13.15 (B4)
unnamed: A5.9 (GPIO6), U13.14 (B5)
unnamed: A5.10 (GPIO7), U13.13 (B6)
unnamed: A5.11 (GPIO8), U13.12 (B7)
unnamed: A5.12 (GPIO9), U13.11 (B8)
unnamed: A5.14 (GPIO10), U14.18 (B1)
unnamed: A5.15 (GPIO11), U14.17 (B2)
unnamed: A5.16 (GPIO12), U14.16 (B3)
unnamed: A5.17 (GPIO13), U14.15 (B4)
unnamed: A5.19 (GPIO14), U14.14 (B5)
unnamed: A5.20 (GPIO15), U14.13 (B6)
unnamed: A5.21 (GPIO16), U14.12 (B7)
unnamed: A5.22 (GPIO17), U14.11 (B8)
unnamed: A5.24 (GPIO18), U15.18 (B1)
unnamed: A5.25 (GPIO19), U15.17 (B2)
unnamed: A5.26 (GPIO20), U15.16 (B3)
unnamed: A5.27 (GPIO21), U15.15 (B4)
unnamed: A5.29 (GPIO22), U15.14 (B5)
unnamed: A5.31 (GPIO26_ADC0), U15.13 (B6)
unnamed: A5.32 (GPIO27_ADC1), U15.12 (B7)
unnamed: A5.34 (GPIO28_ADC2), U15.11 (B8)
unnamed: D1.2 (A), R1.2
unnamed: D2.2 (A), R2.2
unnamed: D3.2 (A), R3.2
unnamed: J1.79 (A0), J8.5, J28.3
unnamed: J1.80 (A1), J8.7, J28.4
unnamed: J1.81 (A2), J8.9, J28.5
unnamed: J1.31 (A3), J4.9, J24.5
unnamed: J1.30 (A4), J4.7, J24.4
unnamed: J1.29 (A5), J4.5, J24.3
unnamed: J1.82 (A6), J8.11, J28.6
unnamed: J1.83 (A7), J8.13, J28.7
unnamed: J1.84 (A8), J8.15, J28.8
unnamed: J1.34 (A9), J4.15, J24.8
unnamed: J1.37 (A10), J4.21, J24.11
unnamed: J1.87 (A11), J8.21, J28.11
unnamed: J1.33 (A12), J4.13, J24.7
unnamed: J1.85 (A13), J8.17, J28.9
unnamed: J1.86 (A14), J8.19, J28.10
unnamed: J1.32 (A15), J4.11, J24.6
unnamed: J1.16 (A16), J3.3, J23.2
unnamed: J1.17 (A17), J3.5, J23.3
unnamed: J1.15 (A18), J3.1, J23.1
unnamed: J1.59 (A19), J6.13, J26.7
unnamed: J1.61 (A20), J6.17, J26.9
unnamed: J1.62 (A21), J6.19, J26.10
unnamed: J1.63 (A22), J6.21, J26.11
unnamed: J1.64 (A23), J6.23, J26.12
unnamed: J1.49 (CLOCK), J5.21, J25.11
unnamed: J1.95 (DI0), J9.13, J29.7
unnamed: J1.94 (DI1), J9.11, J29.6
unnamed: J1.41 (DI2), J5.5, J25.3
unnamed: J1.42 (DI3), J5.7, J25.4
unnamed: J1.91 (DI4), J9.5, J29.3
unnamed: J1.92 (DI5), J9.7, J29.4
unnamed: J1.93 (DI6), J9.9, J29.5
unnamed: J1.43 (DI7), J5.9, J25.5
unnamed: J1.36 (DO0), J4.19, J24.10
unnamed: J1.35 (DO1), J4.17, J24.9
unnamed: J1.88 (DO2), J8.23, J28.12
unnamed: J1.89 (DO3), J9.1, J29.1
unnamed: J1.38 (DO4), J4.23, J24.12
unnamed: J1.39 (DO5), J5.1, J25.1
unnamed: J1.40 (DO6), J5.3, J25.2
unnamed: J1.90 (DO7), J9.3, J29.2
unnamed: J1.68 (MWRT), J7.7, J27.4
unnamed: J1.24 (PHI), J3.19, J23.10
unnamed: J1.72 (RDY), J7.15, J27.8
unnamed: J1.3 (XRDY), J2.1, J22.1
unnamed: J1.78 (pDBIN), J8.3, J28.2
unnamed: J1.26 (pHLDA), J3.23, J23.12
unnamed: J1.76 (pSYNC), J7.23, J27.12
unnamed: J1.48 (sHLTA), J5.19, J25.10
unnamed: J1.46 (sINP), J5.15, J25.8
unnamed: J1.96 (sINTA), J9.15, J29.8
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

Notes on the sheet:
https://github.com/johnwinans/2070-S-100-bus-analyzer
Copyright (C) 2026 John Winans This documentation describes Open Hardware and is licensed under the CERN OHL v. 1.2. You may redistribute and modify this documentation under the terms of the CERN OHL v.1.2. (http://ohwr.org/cernohl). This documentation is distributed WITHOUT ANY EXPRESS OR IMPLIED 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

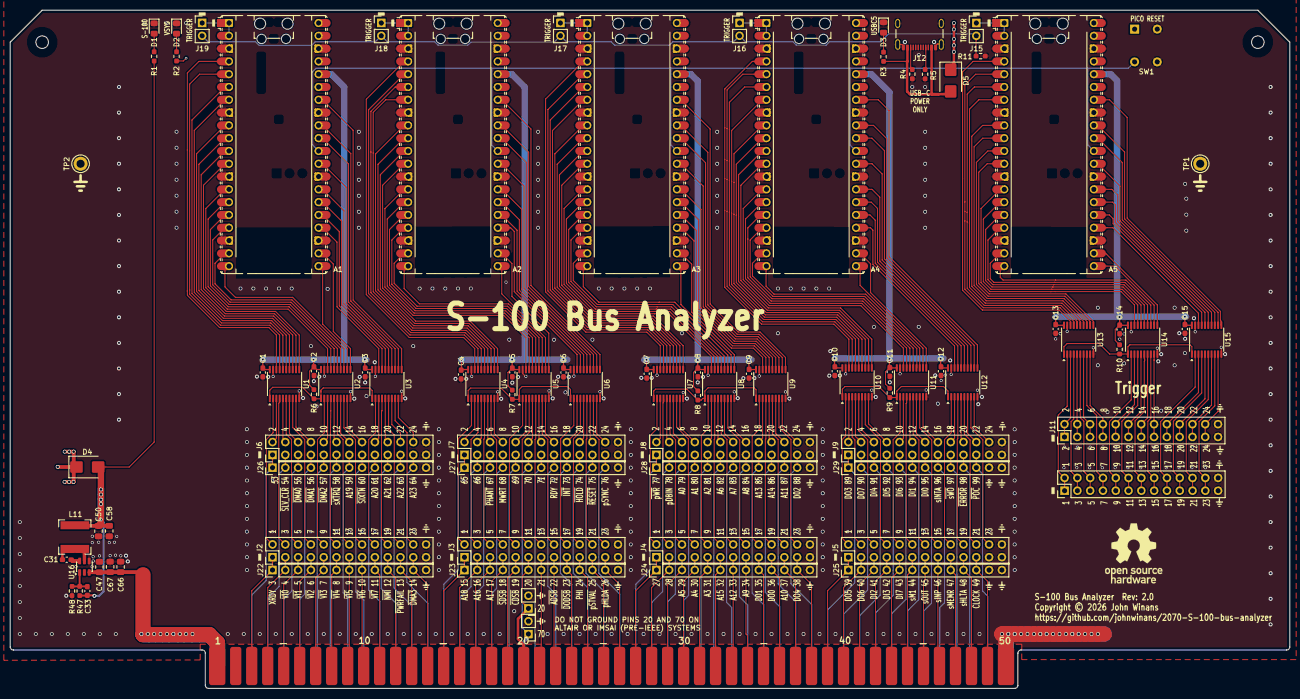
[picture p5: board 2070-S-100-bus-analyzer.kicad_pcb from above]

Board: 4 copper layers, 254.0 x 134.6 mm, 96 parts (1 on the bottom side), 364 nets.

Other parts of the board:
LOGO1#2: OSHW_Logo; OSHW-Logo_11.4x12mm_SilkScreen

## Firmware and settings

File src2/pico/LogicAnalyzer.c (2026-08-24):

#include "LogicAnalyzer_Board_Settings.h"

#include <stdio.h>
#include <string.h>
#include "pico/stdlib.h"
#include "hardware/dma.h"
#include "hardware/pio.h"
#include "hardware/clocks.h"
#include "hardware/flash.h"
#include "hardware/vreg.h"
#include "pico/multicore.h"
#include "LogicAnalyzer.pio.h"
#include "LogicAnalyzer_Structs.h"
#include "LogicAnalyzer_Capture.h"
#include "hardware/structs/syscfg.h"
#include "hardware/structs/systick.h"
#include "tusb.h"
#include "pico/unique_id.h"
#include "pico/bootrom.h"

#ifdef WS2812_LED
    #include "LogicAnalyzer_W2812.h"
#endif

#if defined (CYGW_LED) || defined(USE_CYGW_WIFI)

    #include "pico/cyw43_arch.h"

    #ifdef USE_CYGW_WIFI

        #include "Event_Machine.h"
        #include "Shared_Buffers.h"
        #include "LogicAnalyzer_WiFi.h"
        #include "hardware/regs/usb.h"
        #include "hardware/structs/usb.h"

        bool usbDisabled = false;
        bool cywReady = false;
        bool skipWiFiData = false;
        bool dataFromWiFi = false;
        EVENT_FROM_WIFI wifiEventBuffer;
        WIFI_SETTINGS_REQUEST* wReq;

        #define MULTICORE_LOCKOUT_TIMEOUT (uint64_t)10 * 365 * 24 * 60 * 60 * 1000 * 1000

    #endif

#endif

#if defined (GPIO_LED)
    #define INIT_LED() {\
                            gpio_init(LED_IO); \
                            gpio_set_dir(LED_IO, GPIO_OUT); \
                        }
    #define LED_ON() gpio_put(LED_IO, 1)
    #define LED_OFF() gpio_put(LED_IO, 0)
#elif defined (CYGW_LED)

    #define INIT_LED() { }

    #ifdef USE_CYGW_WIFI
        #define LED_ON() {\
        EVENT_FROM_FRONTEND lonEvt;\
        lonEvt.event = LED_ON;\
        event_push(&frontendToWifi, &lonEvt);\
        }

        #define LED_OFF() {\
        EVENT_FROM_FRONTEND loffEvt;\
        loffEvt.event = LED_OFF;\
        event_push(&frontendToWifi, &loffEvt);\
        }
    #else
        #define LED_ON() cyw43_arch_gpio_put(CYW43_WL_GPIO_LED_PIN, 1)
        #define LED_OFF() cyw43_arch_gpio_put(CYW43_WL_GPIO_LED_PIN, 0)
    #endif

#elif defined (WS2812_LED)
    #define INIT_LED() init_rgb()
    #define LED_ON() send_rgb(0,32,0)
    #define LED_OFF() send_rgb(0,0,32)
#elif defined (NO_LED)
    #define INIT_LED() { }
    #define LED_ON() { }
    #define LED_OFF() { }
#endif

#define MESSAGE_BUFFER_SIZE	128
//Buffer used to store received data
uint8_t messageBuffer[MESSAGE_BUFFER_SIZE];
//Position in the buffer
uint8_t bufferPos = 0;
//Capture status
bool capturing = false;

bool blink = false;
uint32_t blinkCount = 0;

//Capture request pointer
CAPTURE_REQUEST* req;

#ifdef USE_CYGW_WIFI

/// @brief Stores a new WiFi configuration in the flash of the device
/// @param settings Settings to store
void storeSettings(WIFI_SETTINGS* settings)
{
    uint8_t buffer[FLASH_PAGE_SIZE];
    memcpy(buffer, settings, sizeof(WIFI_SETTINGS));
    //multicore_lockout_start_blocking ();
    multicore_lockout_start_timeout_us(MULTICORE_LOCKOUT_TIMEOUT);

    uint32_t intStatus = save_and_disable_interrupts();

    flash_range_erase(FLASH_SETTINGS_OFFSET, FLASH_SECTOR_SIZE);

    for(int buc = 0; buc < 1000; buc++)
    {
        asm("nop");
        asm("nop");
        asm("nop");
        asm("nop");
        asm("nop");
    }

    flash_range_program(FLASH_SETTINGS_OFFSET, buffer, FLASH_PAGE_SIZE);

    for(int buc = 0; buc < 1000; buc++)
    {
        asm("nop");
        asm("nop");
        asm("nop");
        asm("nop");
        asm("nop");
    }

    restore_interrupts(intStatus);

    bool unlocked = false;

    do {
        unlocked = multicore_lockout_end_timeout_us(MULTICORE_LOCKOUT_TIMEOUT);
    } while(!unlocked);

    sleep_ms(500);

}

#endif

/// @brief Transfer a buffer of data through USB using the TinyUSB CDC functions
/// @param data Buffer of data to transfer
/// @param len Length of the buffer
static void cdc_transfer(unsigned char* data, int len)
{

    int left = len;
    int pos = 0;

    while(left > 0)
    {
        int avail = (int) tud_cdc_write_available();
#if 0
		if(avail > 16)
			avail = 16;
#endif
        if(avail > left)
            avail = left;

        if(avail)
        {
            int transferred = (int) tud_cdc_write(data + pos, avail);
            tud_task();
            tud_cdc_write_flush();
            tud_task();
            
            pos += transferred;
            left -= transferred;
        }
        else
        {
            tud_task();
            tud_cdc_write_flush();
            tud_task();
            if (!tud_cdc_connected())
                break;
        }
    }
}

/// @brief Sends a response message to the host application in string mode
/// @param response The message to be sent (null terminated)
/// @param toWiFi If true the message is sent to a WiFi endpoint, else to the USB connection through STDIO
static void sendResponse(const char* response, bool toWiFi)
{
    #ifdef USE_CYGW_WIFI
    if(toWiFi)
    {
        EVENT_FROM_FRONTEND evt;
        evt.event = SEND_DATA;
        evt.dataLength = strlen(response);
        memset(evt.data, 0, 32);
        memcpy(evt.data, response, evt.dataLength);
        event_push(&frontendToWifi, &evt);
    }
    else
    #endif
	{
#if 1
		cdc_transfer( (unsigned char*)response, strlen(response) );
#else
        printf(response);
#endif
	}
}


#ifdef USE_CYGW_WIFI
/// @brief Transfer a buffer of data through WiFi
/// @param data Buffer of data to transfer
/// @param len Length of the buffer
void wifi_transfer(unsigned char* data, int len)
{
    EVENT_FROM_FRONTEND evt;
    evt.event = SEND_DATA;

    int pos = 0;
    int filledData;
    while(pos < len)
    {
        filledData = 0;
        while(pos < len && filledData < 32)
        {
            evt.data[filledData] = data[pos];
            pos++;
            filledData++;
        }

        evt.dataLength = filledData;
        event_push(&frontendToWifi, &evt);
    }
}
#endif

/// @brief Processes data received from the host application
/// @param data The received data
/// @param length Length of the data
/// @param fromWiFi If true the message comes from a WiFi connection
static void processData(uint8_t* data, uint length, bool fromWiFi)
{
    for(uint pos = 0; pos < length; pos++)
    {
        //Store char in buffer and increment position
        messageBuffer[bufferPos++] = data[pos];

		// if we EVER see an 0x55, then we MUST be at the start or end of a message, else reset thy self
		if(messageBuffer[bufferPos-1] == 0x55)
		{
			if (bufferPos == 1)
			{ }									// normal start of message
			else if (bufferPos > 3 && messageBuffer[bufferPos - 2] == 0xAA) 
			{ }									// normal end of message
			else 
			{
				// Received a false start or a truncated message, assume this is the start of a new message 
				messageBuffer[0] = 0x55;
				bufferPos = 1;
			}
		}
        
        //If we have stored the first byte and it is not 0x55 restart reception
        if(bufferPos == 1 && messageBuffer[0] != 0x55)
            bufferPos = 0;
        else if(bufferPos == 2 && messageBuffer[1] != 0xAA) //If we have stored the second byte and it is not 0xAA restart reception
            bufferPos = 0;
        else if(bufferPos >= MESSAGE_BUFFER_SIZE) //Have we overflowed the buffer? then inform to the host and restart reception
        {
            sendResponse("ERR_MSG_OVERFLOW\n", fromWiFi);
            bufferPos = 0;
        }
        else if(bufferPos > 2) //Try to parse the data
        {
            if(messageBuffer[bufferPos - 2] == 0xAA && messageBuffer[bufferPos - 1] == 0x55) //Do we have the stop condition?
            {

                //Yes, unescape the buffer,
                int dest = 0;

                for(int src = 0; src < bufferPos; src++)
                {
                    if(messageBuffer[src] == 0xF0)
                    {
                        messageBuffer[dest] = messageBuffer[src + 1] ^ 0xF0;
                        src++;
                    }
                    else
                        messageBuffer[dest] = messageBuffer[src];

                    dest++;
                }

                switch(messageBuffer[2]) //Check the command we received
                {

                    case 0: //ID request

                        if(bufferPos != 5) //Malformed message?
                            sendResponse("ERR_UNKNOWN_MSG\n", fromWiFi);
                        else
                        {
                            sendResponse("LOGIC_ANALYZER_"BOARD_NAME"_"FIRMWARE_VERSION"\n", fromWiFi);

                            char msg[64];
                            
                            sprintf(msg, "FREQ:%d\n", MAX_FREQ);
                            sendResponse(msg, fromWiFi);
                            sprintf(msg, "BLASTFREQ:%d\n", MAX_BLAST_FREQ);
                            sendResponse(msg, fromWiFi);
                            sprintf(msg, "BUFFER:%d\n", CAPTURE_BUFFER_SIZE);
                            sendResponse(msg, fromWiFi);
                            sprintf(msg, "CHANNELS:%d\n", MAX_CHANNELS);
                            sendResponse(msg, fromWiFi);
                        }
                        break;

                    case 1: //Capture request
                        
                        req = (CAPTURE_REQUEST*)&messageBuffer[3]; //Get the request pointer
                        
                        bool started = false;

                        #ifdef SUPPORTS_COMPLEX_TRIGGER

                            if(req->triggerType == 1) //Start complex trigger capture
                                started = StartCaptureComplex(req->frequency, req->preSamples, req->postSamples, (uint8_t*)&req->channels, req->channelCount, req->trigger, req->count, req->triggerValue, req->captureMode);
                            else if(req->triggerType == 2) //start fast trigger capture
                                started = StartCaptureFast(req->frequency, req->preSamples, req->postSamples, (uint8_t*)&req->channels, req->channelCount, req->trigger, req->count, req->triggerValue, req->captureMode);
                            else if(req->triggerType == 3)
                                started = StartCaptureBlast(req->frequency, req->postSamples, (uint8_t*)&req->channels, req->channelCount, req->trigger, req->inverted, req->captureMode);
                            else //Start simple trigger capture
                                started = StartCaptureSimple(req->frequency, req->preSamples, req->postSamples, req->loopCount, req->measure, (uint8_t*)&req->channels, req->channelCount, req->trigger, req->inverted, req->captureMode);
                        
                        #else

                            if(req->triggerType == 1 || req->triggerType == 2)
                            {
                                sendResponse("CAPTURE_ERROR\n", fromWiFi);
                                break;
                            }
                            else if(req->triggerType == 3)
                                started = StartCaptureBlast(req->frequency, req->postSamples, (uint8_t*)&req->channels, req->channelCount, req->trigger, req->inverted, req->captureMode);
                            else //Start simple trigger capture
                                started = StartCaptureSimple(req->frequency, req->preSamples, req->postSamples, req->loopCount, req->measure, (uint8_t*)&req->channels, req->channelCount, req->trigger, req->inverted, req->captureMode);
                        
                        #endif

                        if(started) //If started successfully inform to the host
                        {
                            sendResponse("CAPTURE_STARTED\n", fromWiFi);
                            capturing = true;
                        }
                        else
                            sendResponse("CAPTURE_ERROR\n", fromWiFi); //Else notify the error

                        break;
                    
                    #ifdef USE_CYGW_WIFI

                    case 2: //Update WiFi settings

                        wReq = (WIFI_SETTINGS_REQUEST*)&messageBuffer[3];
                        WIFI_SETTINGS settings;
                        settings.checksum = 0;
                        memcpy(settings.apName, wReq->apName, 33);
                        memcpy(settings.passwd, wReq->passwd, 64);
                        memcpy(settings.ipAddress, wReq->ipAddress, 16);
                        settings.port = wReq->port;

                        for(int buc = 0; buc < 33; buc++)
                            settings.checksum += settings.apName[buc];

                        for(int buc = 0; buc < 64; buc++)
                            settings.checksum += settings.passwd[buc];

                        for(int buc = 0; buc < 16; buc++)
                            settings.checksum += settings.ipAddress[buc];

                        settings.checksum += settings.port;

                        settings.checksum += 0x0f0f;

                        storeSettings(&settings);

                        wifiSettings = settings;

                        EVENT_FROM_FRONTEND evt;
                        evt.event = CONFIG_RECEIVED;
                        event_push(&frontendToWifi, &evt);

                        sendResponse("SETTINGS_SAVED\n", fromWiFi);

                        break;

                    case 3: //Read power status

                        if(!fromWiFi)
                            sendResponse("ERR_UNSUPPORTED\n", fromWiFi);
                        else 
                        {
                            EVENT_FROM_FRONTEND powerEvent;
                            powerEvent.event = GET_POWER_STATUS;
                            event_push(&frontendToWifi, &powerEvent);
                        }
                        
                        break;

                    #else

                    case 2:
                    case 3:

                        sendResponse("ERR_UNSUPPORTED\n", fromWiFi);
                        break;

                    #endif

                    case 4:

                        sendResponse("RESTARTING_BOOTLOADER\n", fromWiFi);
                        sleep_ms(1000);
                        reset_usb_boot(0, 0);
                        break;

                    case 5:

                        blink = true;
                        blinkCount = 0;
                        sendResponse("BLINKON\n", fromWiFi);
                        break;

                    case 6:

                        blink = false;
                        blinkCount = 0;
                        sendResponse("BLINKOFF\n", fromWiFi);
                        LED_ON();
                        break;

                    default:

                        sendResponse("ERR_UNKNOWN_MSG\n", fromWiFi); //Unknown message
                        break;

                }

                bufferPos = 0; //Reset buffer position
            }
        }
    }
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
int main()
{
    #if defined (TURBO_MODE)

        vreg_disable_voltage_limit();
        vreg_set_voltage(VREG_VOLTAGE_1_30);
        sleep_ms(100);
        
        //Overclock Powerrrr!
        set_sys_clock_khz(400000, true);
    
    #else

        set_sys_clock_khz(200000, true);

    #endif

    //Enable systick using CPU clock
    systick_hw->csr = 0x05;

    pico_unique_board_id_t id;
    pico_get_unique_board_id(&id);

    uint16_t delay = 0;

    for(int buc = 0; buc < PICO_UNIQUE_BOARD_ID_SIZE_BYTES; buc++)
        delay += id.id[buc];

    delay = (delay & 0x3ff) + ((delay & 0xFC00) >> 6);

    sleep_ms(delay);

    //Initialize USB stdio
    stdio_init_all();

    #if defined (BUILD_PICO_W) || defined (BUILD_PICO_2_W)
        cyw43_arch_init();
    #elif defined (BUILD_PICO_W_WIFI) || defined (BUILD_PICO_2_W_WIFI)
        event_machine_init(&wifiToFrontend, wifiEvent, sizeof(EVENT_FROM_WIFI), 8);
            multicore_launch_core1(runWiFiCore);
            while(!cywReady)
                event_process_queue(&wifiToFrontend, &wifiEventBuffer, 1);
    #endif

    //A bit of delay, if the program tries to send data before Windows has identified the device it may crash
    sleep_ms(1000);

    //Clear message buffer
    memset(messageBuffer, 0, MESSAGE_BUFFER_SIZE);

    //Configure led
    INIT_LED();
    LED_ON();

    while(1)
    {
        //Are we capturing?
        if(capturing)
        {
            //Is the PIO units still working?
            if(!IsCapturing())
            {
                //Retrieve the capture buffer and get info about it.
                uint32_t length, first;
                CHANNEL_MODE mode;
                uint8_t* buffer = GetBuffer(&length, &first, &mode);

                uint8_t stampsLength;
                volatile uint32_t* timestamps = GetTimestamps(&stampsLength);

                //Send the data to the host
                uint8_t* lengthPointer = (uint8_t*)&length;

                //Send capture length
                

                #ifdef USE_CYGW_WIFI

                    if(usbDisabled)
                    {
                        sleep_ms(2000);
                        wifi_transfer(lengthPointer, 4);
                    }
                    else
                    {
                        sleep_ms(100);
                        cdc_transfer(lengthPointer, 4);
                    }

                #else
                    sleep_ms(100);
                    cdc_transfer(lengthPointer, 4);
                #endif

                sleep_ms(100);

                //Tanslate sample numbers to byte indexes, makes easier to send data
                switch(mode)
                {
                    case MODE_16_CHANNEL:
                        length *= 2;
                        first *= 2;
                        break;
                    case MODE_24_CHANNEL:
                        length *= 4;
                        first *= 4;
                        break;
                }

                #ifdef USE_CYGW_WIFI

                    //Send the samples
                    if(usbDisabled)
                    {
                        if(first + length > CAPTURE_BUFFER_SIZE)
                        {
                            wifi_transfer(buffer + first, CAPTURE_BUFFER_SIZE - first);
                            wifi_transfer(buffer, (first + length) - CAPTURE_BUFFER_SIZE);
                        }
                        else
                            wifi_transfer(buffer + first, length);

                        wifi_transfer(&stampsLength, 1);

                        if(stampsLength > 1)
                            wifi_transfer((unsigned char*)timestamps, stampsLength * 4);
                    }
                    else
                    {
                        if(first + length > CAPTURE_BUFFER_SIZE)
                        {
                            cdc_transfer(buffer + first, CAPTURE_BUFFER_SIZE - first);
                            cdc_transfer(buffer, (first + length) - CAPTURE_BUFFER_SIZE);
                        }
                        else
                            cdc_transfer(buffer + first, length);

                        cdc_transfer(&stampsLength, 1);

                        if(stampsLength > 1)
                            cdc_transfer((unsigned char*)timestamps, stampsLength * 4);
                    }
                #else

                    if(first + length > CAPTURE_BUFFER_SIZE)
                    {
                        cdc_transfer(buffer + first, CAPTURE_BUFFER_SIZE - first);
                        cdc_transfer(buffer, (first + length) - CAPTURE_BUFFER_SIZE);
                    }
                    else
                        cdc_transfer(buffer + first, length);

                    cdc_transfer(&stampsLength, 1);
                        
                    if(stampsLength > 1)
                        cdc_transfer((unsigned char*)timestamps, stampsLength * 4);

                #endif
                //Done!
                capturing = false;
            }
            else
            {
                LED_OFF();
                sleep_ms(100);

                //Check for cancel request
                if(processCancel())
                {
                    //Stop capture
                    StopCapture();
                    capturing = false;
                    LED_ON();
                }
                else
                {
                    LED_ON();
                    #ifdef SUPPORTS_COMPLEX_TRIGGER
                    check_fast_interrupt();
                    #endif
                    sleep_ms(100);
                }
            }
        }
        else		// not capturing
        {
            if(blink)
            {
                if(blinkCount++ == 200000)
                {
                    LED_OFF();
                }
                else if(blinkCount == 400000)
                {
                    LED_ON();
                    blinkCount = 0;
                }
            }

            processInput(); //Read incomming data
        }
    }

    return 0;
}

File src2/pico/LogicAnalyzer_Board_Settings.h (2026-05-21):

#ifndef __LOGICANALYZER_BOARD_SETTINGS__

    #define __LOGICANALYZER_BOARD_SETTINGS__

    #include "pico/stdlib.h"
    //#include "LogicAnalyzer_Build_Settings.h"

    //Board definitions

    //This defines the name sent to the software
    //#define BOARD_NAME "PICO"

    //If defined the device supports complex, fast and external triggers
    //#define SUPPORTS_COMPLEX_TRIGGER
    
    //Stablishes the channel base GPIO
    //#define INPUT_PIN_BASE 2
    
    //Complex/fast/ext trigger output pin
    //#define COMPLEX_TRIGGER_OUT_PIN 0
    
    //Complex/fast/ext trigger input pin
    //#define COMPLEX_TRIGGER_IN_PIN 1
    
    //If defined, the onboard led is a led connected to a GPIO
    //#define GPIO_LED
    
    //If defined, the onboard led is a led connected to a CYGW module (for the Pico W)
    //#define CYGW_LED
    
    //If defined, the onboard led is a RGB led connected to a GPIO
    //#define WS2812_LED
    
    //If defined, the board has no LED
    //#define NO_LED
    
    //Defines the used GPIO used for the GPIO and WS2812 led types
    //#define LED_IO 25
    
    //If defined enables the Pico W WiFi module
    //#define USE_CYGW_WIFI
    
    //Defines the pin map for the PIO
    //Include ALWAYS an entry for the COMPLEX_TRIGGER_IN_PIN even if not used, you can repeat a pin if needed
    //If COMPLEX_TRIGGER is supported remember to set the first 16 channels to be consecutive
    //#define PIN_MAP {2,3,4,5,6,7,8,9,10,11,12,13,14,15,16,17,18,19,20,21,22,26,27,28,COMPLEX_TRIGGER_IN_PIN}
    
    //Defines the maximum capture buffer size
    //#define CAPTURE_BUFFER_SIZE (128 * 1024)
    
    //Defines the maximum number of channels
    //#define MAX_CHANNELS 24
    
    //Defines the maximum frequency for the capture in normal mode
    //#define MAX_FREQ 200000000
    
    //Defines the maximum frequency for the capture in blast mode
    //#define MAX_BLAST_FREQ 400000000
    
    //If the board supports TURBO mode (400Mhz overclock) then you can define two sets of frequencies using
    //#ifdef TURBO_MODE / #else / #endif
    
    #if defined (BUILD_PICO)

        #define BOARD_NAME "PICO"
        #define SUPPORTS_COMPLEX_TRIGGER
        #define INPUT_PIN_BASE 2
        #define COMPLEX_TRIGGER_OUT_PIN 0
        #define COMPLEX_TRIGGER_IN_PIN 1
        #define GPIO_LED
        #define LED_IO 25
        #define PIN_MAP {2,3,4,5,6,7,8,9,10,11,12,13,14,15,16,17,18,19,20,21,22,26,27,28,COMPLEX_TRIGGER_IN_PIN}

        #ifdef TURBO_MODE
            #define MAX_FREQ 200000000
            #define MAX_BLAST_FREQ 400000000
        #else
            #define MAX_FREQ 100000000
            #define MAX_BLAST_FREQ 200000000
        #endif
        #define CAPTURE_BUFFER_SIZE (128 * 1024)
        #define MAX_CHANNELS 24

    #elif defined (BUILD_PICO_2)

        #define BOARD_NAME "PICO_2"
        #define SUPPORTS_COMPLEX_TRIGGER
        #define INPUT_PIN_BASE 2
        #define COMPLEX_TRIGGER_OUT_PIN 0
        #define COMPLEX_TRIGGER_IN_PIN 1
        #define GPIO_LED
        #define LED_IO 25
        #define PIN_MAP {2,3,4,5,6,7,8,9,10,11,12,13,14,15,16,17,18,19,20,21,22,26,27,28,COMPLEX_TRIGGER_IN_PIN}

        #ifdef TURBO_MODE
            #define MAX_FREQ 200000000
            #define MAX_BLAST_FREQ 400000000
        #else
            #define MAX_FREQ 100000000
            #define MAX_BLAST_FREQ 200000000
        #endif
        #define CAPTURE_BUFFER_SIZE (128 * 3 * 1024)
        #define MAX_CHANNELS 24

    #elif defined (BUILD_PICO_W)

        #define BOARD_NAME "W"
        #define SUPPORTS_COMPLEX_TRIGGER
        #define INPUT_PIN_BASE 2
        #define COMPLEX_TRIGGER_OUT_PIN 0
        #define COMPLEX_TRIGGER_IN_PIN 1
        #define CYGW_LED
        #define PIN_MAP {2,3,4,5,6,7,8,9,10,11,12,13,14,15,16,17,18,19,20,21,22,26,27,28,COMPLEX_TRIGGER_IN_PIN}

        #define MAX_FREQ 100000000
        #define MAX_BLAST_FREQ 200000000
        #define CAPTURE_BUFFER_SIZE (128 * 1024)
        #define MAX_CHANNELS 24

    #elif defined (BUILD_PICO_W_WIFI)

        #define BOARD_NAME "WIFI"
        #define SUPPORTS_COMPLEX_TRIGGER
        #define INPUT_PIN_BASE 2
        #define COMPLEX_TRIGGER_OUT_PIN 0
        #define COMPLEX_TRIGGER_IN_PIN 1
        #define CYGW_LED
        #define USE_CYGW_WIFI
        #define PIN_MAP {2,3,4,5,6,7,8,9,10,11,12,13,14,15,16,17,18,19,20,21,22,26,27,28,COMPLEX_TRIGGER_IN_PIN}
        #define MAX_FREQ 100000000
        #define MAX_BLAST_FREQ 200000000
        #define CAPTURE_BUFFER_SIZE (128 * 1024)
        #define MAX_CHANNELS 24
        
    #elif defined (BUILD_PICO_2_W)

        #define BOARD_NAME "2_W"
        #define SUPPORTS_COMPLEX_TRIGGER
        #define INPUT_PIN_BASE 2
        #define COMPLEX_TRIGGER_OUT_PIN 0
        #define COMPLEX_TRIGGER_IN_PIN 1
        #define CYGW_LED
        #define PIN_MAP {2,3,4,5,6,7,8,9,10,11,12,13,14,15,16,17,18,19,20,21,22,26,27,28,COMPLEX_TRIGGER_IN_PIN}
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

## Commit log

2026-03-01 Import S-100 template
    [2070-S-100-bus-analyzer.kicad_pcb, 2070-S-100-bus-analyzer.kicad_sch]
2026-03-15 Re-start project from new KiCad9 S-100 template
    [2070-S-100-bus-analyzer.kicad_pcb, 2070-S-100-bus-analyzer.kicad_sch]
2026-03-21 Add S100 power
    [2070-S-100-bus-analyzer.kicad_pcb, 2070-S-100-bus-analyzer.kicad_sch]
2026-03-24 Acute angles
    [2070-S-100-bus-analyzer.kicad_pcb]
2026-03-25 Rounded edge fingers curved teardrops improve finger edge clearance
    [2070-S-100-bus-analyzer.kicad_pcb, 2070-S-100-bus-analyzer.kicad_sch]
2026-03-25 DRC cleanup on edge fingers
    [2070-S-100-bus-analyzer.kicad_pcb]
2026-03-25 DRC cleanup
    [2070-S-100-bus-analyzer.kicad_pcb]
2026-03-25 power supply routing
    [2070-S-100-bus-analyzer.kicad_pcb, 2070-S-100-bus-analyzer.kicad_sch]
2026-03-26 DRC fixes Clean up power supplies
    [2070-S-100-bus-analyzer.kicad_pcb, 2070-S-100-bus-analyzer.kicad_sch]
2026-03-27 Add title block
    [2070-S-100-bus-analyzer.kicad_sch]
2026-03-27 update power supply as per wiggle
    [2070-S-100-bus-analyzer.kicad_pcb, 2070-S-100-bus-analyzer.kicad_sch]
2026-03-27 Add pin-1 markers
    [2070-S-100-bus-analyzer.kicad_pcb, 2070-S-100-bus-analyzer.kicad_sch]
2026-03-28 cosmetic stuff add gnd stiching vias
    [2070-S-100-bus-analyzer.kicad_pcb, 2070-S-100-bus-analyzer.kicad_sch]
2026-03-30 Remove OSHW from BOM
    [2070-S-100-bus-analyzer.kicad_sch]
2026-03-31 BOM updates
    [2070-S-100-bus-analyzer.kicad_pcb, 2070-S-100-bus-analyzer.kicad_sch]
2026-04-09 Correct spelling of PHI :-D
    [2070-S-100-bus-analyzer.kicad_pcb]
2026-04-19 Change trigger pulldown to 2.2K
    [2070-S-100-bus-analyzer.kicad_sch]
2026-04-19 Rename /pDBIN as pDBIN & update silk
    [2070-S-100-bus-analyzer.kicad_pcb, 2070-S-100-bus-analyzer.kicad_sch]
2026-04-19 Change /pSYNC to pSYNC & fix silk Larger testoints for gators
    [2070-S-100-bus-analyzer.kicad_pcb, 2070-S-100-bus-analyzer.kicad_sch]
2026-04-21 Add some part info
    [2070-S-100-bus-analyzer.kicad_sch]
2026-05-07 Remove linear regulator option
    [2070-S-100-bus-analyzer.kicad_pcb, 2070-S-100-bus-analyzer.kicad_sch]
2026-05-08 Add 3rd header row, note pins20/70, fonts, BOM
    [2070-S-100-bus-analyzer.csv, 2070-S-100-bus-analyzer.kicad_pcb, 2070-S-100-bus-analyzer.kicad_sch]
2026-05-21 Fix messageBuffer overrun Message block resync fix Speed up main loop by flashing LED faster
    [LogicAnalyzer.c]
2026-05-24 Reverse printing order of CSV output
2026-08-18 fix hardcoded messageBuffer length
    [LogicAnalyzer.c]
2026-08-24 Remove LED debug hack

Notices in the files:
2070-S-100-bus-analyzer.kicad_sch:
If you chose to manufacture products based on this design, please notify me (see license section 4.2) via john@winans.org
